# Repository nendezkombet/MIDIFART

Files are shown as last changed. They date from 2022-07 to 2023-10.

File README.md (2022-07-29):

# MIDIFART
Pocket midi controller

MIDIFART is a pocket midi controller designed for Arduino Promini that supports five analog potentiometer, 10 buttons, 1 bank button, some modules and midi output capability via 3.5mm TRS cable for sending data out to hardware synthesizer or midi device, and some modules supported. For programing code can be done with arduinoIDE. The PCB board also support Arduino Promicro as midi device for software controller but sadly you don't have full features like some optional module but it is more than enough for backing up your task. 

Designer and maintainer: [sandipratama/nendezkombet](https://github.com/nendezkombet) 

## Table of contents

- [Features](#features)
- [Midifart](#midifart)
- [PCB](#pcb)
- [BOM](#bom)
- [Case](#case)
- [Assembly Guide](#assembly-guide)

## Features

- Low cost build.
- Multi layout support.
- Easy to source components.
- Easy to build.
- Arduino Promini and Promicro compatible.
- 10 buttons with RGB support.
- 6 analog potentiometer support.
- Midi out support.
- Oled lcd support.
- Battery powered support ( as portable controller ).
- And more.

## Midifart

IMG_E0225



## PCB

Top view

IMG_E0231

Bottom view

IMG_E0233

## BOM

|Parts|Footprint|Quantity|
|:---|:---|:---|
|WS2812B RGB LED |5050|10|
|100nF capacitor|0805|10|
|12mm tactile switch |4 pin|10|
|12mm tactile switch caps ||10|
|6x10mm tactile switch|4 pin|1|
|Arduino Promini or Promicro |3.3v or 5v|1|
|10K pullup resistor (optional)|axial or 0805|11| 
|220ohm resistor (depend on mcu voltage)|axial or 0805|4| 
|10ohm resistor (depend on mcu voltage)|axial or 0805|1| 
|22ohm resistor (depend on mcu voltage)|axial or 0805|1| 
|B10K Analog potentiometer | RV09 or RK09|5|
|3.5mm TRS female socket |PJ313|1|
|Micro slide switch (optional)|MSS22D18 |1|
|3.7v-9V battery pack (depend on mcu voltage)||1|
|8mm M3 "MALE TO FEMALE" brass standoff||4|
|12mm M3 "FEMALE TO FEMALE" brass standoff||4|
|6mm M3 screw|-|8|
|SSD1306 oled lcd (optional)|0.96 inch|1| 
|HC-SR04 (optional)|distance module |1| 
|3mm led (optional)|mono color|2| 
|2pin molex socket|2.54 pitch|1|
|3.5mm TRS jack to 5-pin midi din male socket|see detail below|1|

51kXivjBTuL _AC_SX425_

you can build by your self, wiring instruction can by found out there.

Male TRS jack to female TRS jack socket wiring  :

|Male|Female|
|:---|:---|
|Tip | VCC |
|Ring | TX |
|Sleeve  | GROUND |

Because there are a few Promini variant, so for this project i recomended using compatible Promini variant and pinout configuration like in the picture below :

ha-7006-027-2

If you decide use Arduino Promini 3.3v or 5v you will need USB to TTL converter like in picture below :

"DO NOT FORGET CHECKING THE VOLTAGE SWITCH MUST BE MATCHING WITH YOUR MCU OPERATING VOLTAGE !!!"

ft232rl-ftdi-usb-zu-ttl-serial-adapter-modul-33v-5v

## Case

Use 3mm acrylic plate like pictures above.

## Assembly Guide

See inside "case" folder !!!

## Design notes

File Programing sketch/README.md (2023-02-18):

Before you upload the code into controller you need install some arduinoIDE library.
library requirements :

- Control Surface library https://github.com/tttapa/Control-Surface
- USB MIDI library https://github.com/arduino-libraries/MIDIUSB
- Fastled libray
- NewPing library if use ultrasonic sensor

Note :
in this project i'm not expert programer, i spent abouth sixth months just for learning programing language, electrical wiring and PCB design because my curiosity.
But at least i has so much fun and learn something new.
So if anyone expert with programing code maybe can help developeing this project at least tidy up my code are very wellcomed.
And will keep this project update.
for further updated i planed adding midi input and some features.

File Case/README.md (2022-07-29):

MIDIFART Assembly guide.

1. Prepare all the components and see PCB legend below for components pacement
2. solder pin header first ( just pin header without MCU )
3. Solder 100nf capacitors ( this is optional component )
4. Solder RGB leds if use ( this is optional component )
5. Solder all components that placed in the top of MCU ( make sure no component leave behind )
6. Than go on with other parts
7. If all done double check everything especialy for solder joint
8. Solder your MCU, because this part permanently attached in the PCB just make sure no mistake in every step you did before.
9. Upload program code to MCU and test the device





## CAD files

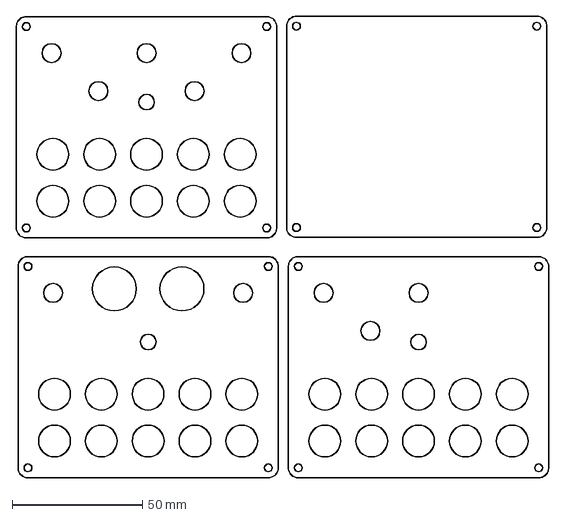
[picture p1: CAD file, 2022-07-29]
Case/midifart plate dxf.dxf
204.5 x 177.3 mm

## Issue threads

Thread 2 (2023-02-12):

Consultation on related issues

bobvc133, 2023-02-12:
1. Can you explain item 4 in detail? The resistors and soldering positions used by 5V MCU, and the resistors and soldering positions used by 3.3V MCU, I am a bit confused.
2. How to charge the battery?
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

nendezkombet, 2023-02-13:
hi, if you used 3.3v MCU you need 10ohm resistor and 22ohm resistor and look at the bottom legend  like in the picture above there are two resistor for TRS jack midi connection **"the left side for 10ohm resistor and 22ohm resistor for the right side"** resistor do not have polarity so just solder them, If you used 5v MCU just replace them with 2x 220ohm resistor.

For battery you need detach the battery from controller and charge with charging module like TP4056 or other variant. if i have a time i will upgrade this project including onboard charging module and midi input features.

bobvc133, 2023-02-13:
I use a 5V MCU to upload the program at the same time, but there is no response to the BUTTON1 operation, there is no problem with the line, I don’t know why

nendezkombet, 2023-02-13:
did you mean you use other arduino like nano or uno to upload the sketch to 3.3v promini ? make sure you connect VCC pin on promini to 3.3v on the uno/nano. Than in the IDE select promini with 8Mhz 3.3v varian and upload the sketch.

It's weird if the first button doesn't work, if you have multimeter you can check the switch connection maybe defected switch and try desolder and replace with spare switch you own.

bobvc133, 2023-02-13:
I'm using a 5V promini, and there is no problem with the multimeter test switch and wiring, which is very strange.

bobvc133, 2023-02-14:
Well, I thought of this reason too, but I haven't had time to test it because I don't have a proper power supply, thanks again!

nendezkombet, 2023-02-16:
it's weird, mine working well. Maybe the connection between switch to MCU or MCU breakout to the chip controller.

bobvc133, 2023-02-17:
The promini onboard LED responds when button 1 is operated

nendezkombet, 2023-02-18:
when button1 pressed do actualy sending data? and check the sketch one more time if you miss something!

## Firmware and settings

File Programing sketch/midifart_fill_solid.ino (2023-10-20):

#include <FastLED.h>
#include <Control_Surface.h>


USBMIDI_Interface midi;                                 // uncomment jika menggunakan promicro sebagai USB HID MIDI sebagai software controller
                                                        // uncomment line dibawah ini jika controller di fungsikan sebagai hardware controller                                            
//HardwareSerialMIDI_Interface midi {Serial};           // setting awal serial midi untuk promini yang digunakan dengan 5pin midi din sebagai hardware controller
                                                        // ubah "Serial" ke "Serial1" jika menggunakan promicro dengan 5pin midi din sebagai hardware controller

#define NUM_LEDS 10
#define DATA_PIN 9 
#define FRAMES_PER_SECOND  120
CRGB leds[NUM_LEDS];

CCPotentiometer potentiometers[]= {
  {A3, 75},             // parameter pin potentiometer arduino dan midi CC yang digunakan
  {A2, 74},             // midi CC bisa di ubah sesuai yang di inginkan
  {A1, 73},
  {A0, 72}, 
  {A6, 71}              // A7 pin untuk promini potentiometer ke-5 dan A6 pin untuk promicro potentiometer ke-5  
};

Button buttons[] {
  //13, 10, 3, 8, 5, 12, 11, 2, 7, 6            // array pin dari promini buttons
  15, 10, 3, 8, 5, 14, 16, 2, 7, 6              // array pin dari promicro buttons
};

Button selector = 0;              // Bank selector button
int buttonPushCounter = 0;        // Selector button counter
int buttonState = 0;              // posisi button
int lastButtonState = 0;          // posisi button sebelumnya

template <class T, size_t N> constexpr size_t len(const T (&)[N]) { return N; }

static_assert(len(buttons) == (len(leds)),"midifart");

void setup() {
  
  FastLED.addLeds<WS2812B, DATA_PIN, GRB>(leds, NUM_LEDS); 
  FastLED.setBrightness (40); 
  FastLED.clear();  
  delay(50);
  fill_solid(leds, NUM_LEDS, CRGB::Aqua);
  FastLED.show();
 
  
  Control_Surface.begin();
  //midi.begin();
  for (auto &button : buttons)
  button.begin();
  Keyboard.begin();
}

void loop() {

  Control_Surface.loop();
  
  buttonState = selector.update() == Button::Falling;           // Update pushbutton selector:

  if (buttonState != lastButtonState) {                         // Pembanding status button dengan status sebelumnya
    if (buttonState == selector.update() == Button::Rising) {
      buttonPushCounter++;
    }
  }

  lastButtonState = buttonState;                                
  if (buttonPushCounter % 4 == 0) {                             
    buttonPushCounter = 0;
    }

  switch (buttonPushCounter) {

    case 0 : 
    tonemode1();
    FastLED.setBrightness (20); 
    fill_solid(leds, NUM_LEDS, CRGB::Aqua);
    FastLED.show();    
    

    break;
    
    case 1 : 
    tonemode2();
    FastLED.setBrightness (40); 
    fill_solid(leds, NUM_LEDS, CRGB::Olive);
    FastLED.show();    

    break;
    
    case 2 : 
    tonemode3();
    FastLED.setBrightness (30); 
    fill_solid(leds, NUM_LEDS, CRGB::Crimson);
    FastLED.show();    
 
    break;

    case 3 : 
    tonemode4();
    FastLED.setBrightness (30); 
    fill_solid(leds, NUM_LEDS, CRGB::Red);
    FastLED.show();    
 
    break;
      }
}


void ccmode() {
  // ketiga constant parameter dibawah sangat berguna jika digunakan untuk mengirim beberapa command secara bersamaan contohnya MSB dan LSB
  // just change the array value as you need
  
  const uint8_t cc[]    { 12, 13, 14, 15, 16, 17, 18, 19, 28, 29 };
  const uint8_t val[]   { 127, 127, 127, 127, 127, 127, 127, 127, 127, 127 };    
  //const uint8_t pc[]    { 0, 1, 2, 3, 4, 5, 6, 7, 8, 9 };
  
  for (uint8_t i = 0; i < len(buttons); ++i) {
    auto state = buttons[i].update();
    if (state == Button::Falling) {
      
      Control_Surface.sendControlChange(cc[i],val[i]);            // Command untuk mengirim midi CC dengan nilai spesifik
      //Control_Surface.sendProgramChange(pc[i]);                 // Kunjungi dokumentasi Control Surface library untuk informasi lebih lanjut
    }
  }
}

void tonemode1() {
  //const uint8_t cc[]  { 32, 32, 32, 32, 32, 32, 32, 32, 32, 32 };
  //const uint8_t val[] { 1, 2, 3, 4, 5, 1, 2, 3, 4, 5 }; 
  //const uint8_t pc[]  { 10, 11, 12, 13, 14, 15, 16, 17, 18, 19 };
  const MIDIAddress noteAddress[]  {{MIDI_Notes::C(3), CHANNEL_1},
                                  {MIDI_Notes::Db(3), CHANNEL_1},
                                  {MIDI_Notes::D(3), CHANNEL_1},
                                  {MIDI_Notes::Eb(3), CHANNEL_1},
                                  {MIDI_Notes::E(3), CHANNEL_1},
                                  {MIDI_Notes::F_(3), CHANNEL_1},
                                  {MIDI_Notes::Gb(3), CHANNEL_1},
                                  {MIDI_Notes::G(3), CHANNEL_1},
                                  {MIDI_Notes::Ab(3), CHANNEL_1},
                                  {MIDI_Notes::A(3), CHANNEL_1}};
  const uint8_t onvelocity[]  { 127, 127, 127, 127, 127, 127, 127, 127, 127, 127 };
  //const uint8_t offvelocity[]  { 0, 0, 0, 0, 0, 0, 0, 0, 0, 0 };
  
  for (uint8_t i = 0; i < len(buttons); ++i) {
    auto state = buttons[i].update();
    if (state == Button::Falling) {
      //Control_Surface.sendControlChange(cc[i],val[i]);
      //Control_Surface.sendProgramChange(pc[i]);
      Control_Surface.sendNoteOn(noteAddress[i], onvelocity[i]);         // send a note dengan spesifik value
    } else if (state == Button::Rising) {
      Control_Surface.sendNoteOff(noteAddress[i], onvelocity[i]); 
      }
  }
}

void tonemode2() {
  //const uint8_t cc[]  { 32, 32, 32, 32, 32, 32, 32, 32, 32, 32 };
  //const uint8_t val[] { 1, 2, 3, 4, 5, 1, 2, 3, 4, 5 }; 
  //const uint8_t pc[]  { 10, 11, 12, 13, 14, 15, 16, 17, 18, 19 };
  const MIDIAddress noteAddress[] {{MIDI_Notes::Bb(3), CHANNEL_1},
                                  {MIDI_Notes::B(3), CHANNEL_1},
                                  {MIDI_Notes::C(4), CHANNEL_1},
                                  {MIDI_Notes::Db(4), CHANNEL_1},
                                  {MIDI_Notes::D(4), CHANNEL_1},
                                  {MIDI_Notes::Eb(4), CHANNEL_1},
                                  {MIDI_Notes::E(4), CHANNEL_1},
                                  {MIDI_Notes::F_(4), CHANNEL_1},
                                  {MIDI_Notes::Gb(4), CHANNEL_1},
                                  {MIDI_Notes::G(4), CHANNEL_1}};
  const uint8_t onvelocity[]  { 127, 127, 127, 127, 127, 127, 127, 127, 127, 127 };
  //const uint8_t offvelocity[]  { 0, 0, 0, 0, 0, 0, 0, 0, 0, 0 };
  
  for (uint8_t i = 0; i < len(buttons); ++i) {
    auto state = buttons[i].update();
    if (state == Button::Falling) {
      //Control_Surface.sendControlChange(cc[i],val[i]);
      //Control_Surface.sendProgramChange(pc[i]);
      Control_Surface.sendNoteOn(noteAddress[i], onvelocity[i]);         // send a note dengan spesifik value
    } else if (state == Button::Rising) {
      Control_Surface.sendNoteOff(noteAddress[i], onvelocity[i]); 
      }
  }
}

void tonemode3() {
  //const uint8_t cc[]  { 32, 32, 32, 32, 32, 32, 32, 32, 32, 32 };
  //const uint8_t val[] { 1, 2, 3, 4, 5, 1, 2, 3, 4, 5 }; 
  //const uint8_t pc[]  { 10, 11, 12, 13, 14, 15, 16, 17, 18, 19 };
  const MIDIAddress noteAddress[]  {{MIDI_Notes::Ab(4), CHANNEL_1},
                                  {MIDI_Notes::A(4), CHANNEL_1},
                                  {MIDI_Notes::Bb(4), CHANNEL_1},
                                  {MIDI_Notes::B(4), CHANNEL_1},
                                  {MIDI_Notes::C(5), CHANNEL_1},
                                  {MIDI_Notes::Db(5), CHANNEL_1},
                                  {MIDI_Notes::D(5), CHANNEL_1},
                                  {MIDI_Notes::Eb(5), CHANNEL_1},
                                  {MIDI_Notes::E(5), CHANNEL_1},
                                  {MIDI_Notes::F_(5), CHANNEL_1}};
  const uint8_t onvelocity[]  { 127, 127, 127, 127, 127, 127, 127, 127, 127, 127 };
  //const uint8_t offvelocity[]  { 0, 0, 0, 0, 0, 0, 0, 0, 0, 0 };
  
  for (uint8_t i = 0; i < len(buttons); ++i) {
    auto state = buttons[i].update();
    if (state == Button::Falling) {
      //Control_Surface.sendControlChange(cc[i],val[i]);
      //Control_Surface.sendProgramChange(pc[i]);
      Control_Surface.sendNoteOn(noteAddress[i], onvelocity[i]);         // send a note dengan spesifik value 
    } else if (state == Button::Rising) {
      Control_Surface.sendNoteOff(noteAddress[i], onvelocity[i]); 
      }
  }
}

void tonemode4() {
  //const uint8_t cc[]  { 32, 32, 32, 32, 32, 32, 32, 32, 32, 32 };
  //const uint8_t val[] { 1, 2, 3, 4, 5, 1, 2, 3, 4, 5 }; 
  //const uint8_t pc[]  { 10, 11, 12, 13, 14, 15, 16, 17, 18, 19 };
  const MIDIAddress noteAddress[]  {{MIDI_Notes::Gb(5), CHANNEL_1},
                                  {MIDI_Notes::G(5), CHANNEL_1},
                                  {MIDI_Notes::Ab(5), CHANNEL_1},
                                  {MIDI_Notes::A(5), CHANNEL_1},
                                  {MIDI_Notes::Bb(5), CHANNEL_1},
                                  {MIDI_Notes::B(5), CHANNEL_1},
                                  {MIDI_Notes::C(6), CHANNEL_1},
                                  {MIDI_Notes::Db(6), CHANNEL_1},
                                  {MIDI_Notes::D(6), CHANNEL_1},
                                  {MIDI_Notes::Eb(6), CHANNEL_1}};
  const uint8_t onvelocity[]  { 127, 127, 127, 127, 127, 127, 127, 127, 127, 127 };
  //const uint8_t offvelocity[]  { 0, 0, 0, 0, 0, 0, 0, 0, 0, 0 };
  
  for (uint8_t i = 0; i < len(buttons); ++i) {
    auto state = buttons[i].update();
    if (state == Button::Falling) {
      //Control_Surface.sendControlChange(cc[i],val[i]);
      //Control_Surface.sendProgramChange(pc[i]);
      Control_Surface.sendNoteOn(noteAddress[i], onvelocity[i]);         // send a note dengan spesifik value 
    } else if (state == Button::Rising) {
      Control_Surface.sendNoteOff(noteAddress[i], onvelocity[i]); 
      }
  }
}

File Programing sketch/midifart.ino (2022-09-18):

#include <FastLED.h>
//#include <NewPing.h>              //uncomment this line if use ultrasonic sensor
#include <Control_Surface.h>


//USBMIDI_Interface midi;                               // uncomment this line if use promicro as USB HID MIDI device as software controller
                                                        // and comment the line below                                                       
HardwareSerialMIDI_Interface midi {Serial};             // default serial midi for promini with 5pin midi din as hardware controller
                                                        // change "Serial" to "Serial1" if you using promicro with 5pin midi din as hardware controller
                                                      
//uncomment all of six line below if you using ultrasonic sensor (only works with promini)                                                     
//#define TRIGGER_PIN  18           // Arduino pin tied to trigger pin on the ultrasonic sensor.
//#define ECHO_PIN     19           // Arduino pin tied to echo pin on the ultrasonic sensor.
//#define MAX_DISTANCE 30           // Maximum distance we want to ping, change this value if necessary (in centimeters)
//int midiMapped = 0;          
//int lastmidiMapped = 0;
//NewPing sonar(TRIGGER_PIN, ECHO_PIN, MAX_DISTANCE);           // NewPing setup of pins and maximum distance.

#define NUM_LEDS 10
#define DATA_PIN 9 
#define FRAMES_PER_SECOND  120
CRGB leds[NUM_LEDS];

int ledState = LOW;
unsigned long previousMillis = 0;
const long interval = 1000; 

CCPotentiometer potentiometers[]= {
  {A3, 11},    // pin address and CC address parameter
  {A2, 74},    // CC address parameter can be edited if you need specific CC address
  {A1, 73},
  {A0, 75}, 
  {A7, 5}      // A7 pin for promini fifth pot and A6 pin for promicro fifth pot
};

Button buttons[] {
  13, 10, 3, 8, 5, 12, 11, 2, 7, 6          // array of promini buttons
  //15, 10, 3, 8, 5, 14, 16, 2, 7, 6        // array of promicro buttons
};

Button selector = 0;         // Bank selector button
int buttonPushCounter = 0;   // counter for the number of button presses
int buttonState = 0;         // current state of the button
int lastButtonState = 0;     // previous state of the button

template <class T, size_t N> constexpr size_t len(const T (&)[N]) { return N; }

static_assert(len(buttons) == (len(leds)),"midifart");

void setup() {
  
  FastLED.addLeds<WS2812B, DATA_PIN, GRB>(leds, NUM_LEDS); 
  FastLED.setBrightness (100);  

  pinMode(18, OUTPUT);      // bank led indicator (promini only)
  pinMode(19, OUTPUT);
  
  Control_Surface.begin();
  midi.begin();
  for (auto &button : buttons)
  button.begin();
}

void loop() {

  Control_Surface.loop();
  
  unsigned long currentMillis = millis(); 
  buttonState = selector.update() == Button::Falling;        // read the pushbutton selector:

  if (buttonState != lastButtonState) {                      //compare the buttonState to its previous state
    if (buttonState == selector.update() == Button::Rising) {
      buttonPushCounter++;
    }
  }

  lastButtonState = buttonState;                             // save the current state as the last state

  if (buttonPushCounter % 3 == 0) {                          // change value "3" to "2" if you just need two bank without sysex mode
    buttonPushCounter = 0;
    }

  switch (buttonPushCounter) {

    case 0 : 
    bank1();
    
  if (currentMillis - previousMillis >= interval) {
    // save the last time you blinked the LED
    previousMillis = currentMillis;

    // if the LED is off turn it on and vice-versa:
    if (ledState == LOW) {
      ledState = HIGH;
    } else {
      ledState = LOW;
    }

    // set the LED with the ledState of the variable:
    digitalWrite(18, ledState);
    digitalWrite(19, LOW);
  } 
    break;
    
    case 1 : 
    bank2();
    
  if (currentMillis - previousMillis >= interval) {
    // save the last time you blinked the LED
    previousMillis = currentMillis;

    // if the LED is off turn it on and vice-versa:
    if (ledState == LOW) {
      ledState = HIGH;
    } else {
      ledState = LOW;
    }

    // set the LED with the ledState of the variable:
    digitalWrite(19, ledState);
    digitalWrite(18, LOW);
  }
    break;
    
    case 2 : 
    sysExmode();
    
  if (currentMillis - previousMillis >= interval) {
    // save the last time you blinked the LED
    previousMillis = currentMillis;

    // if the LED is off turn it on and vice-versa:
    if (ledState == LOW) {
      ledState = HIGH;
    } else {
      ledState = LOW;
    }

    // set the LED with the ledState of the variable:
    digitalWrite(18, ledState);
    digitalWrite(19, ledState);
  }   
    break;
  }
}
    
  //uncomment all of seven line below if you using ultrasonic sensor (only works with promini)
  //float x  = sonar.ping_cm();                          //sensor read
  //midiMapped = map(x, 5, 28, 127, 0);                  //sensor map 5-28 cm converted to cc value 0-127 or 127-0
  //if (lastmidiMapped != midiMapped) {
  //       if (midiMapped >= 0 && midiMapped <= 127) 
  //       midi.sendControlChange(42, midiMapped);        
  //       lastmidiMapped = midiMapped;                  //save last cc value
  //}


void bank1() {
  // three constant parameter below very convenient if you need specific sound between bank to bank or working with MSB and LSB
  // just change the array value as you need
  
  const uint8_t cc[]    { 32, 32, 32, 32, 32, 32, 32, 32, 32, 32 };
  const uint8_t val[]   { 1, 2, 3, 4, 5, 1, 2, 3, 4, 5 };    
  const uint8_t pc[]    { 0, 1, 2, 3, 4, 5, 6, 7, 8, 9 };
  
  for (uint8_t i = 0; i < len(buttons); ++i) {
    auto state = buttons[i].update();
    if (state == Button::Falling) {
      midi.sendControlChange(cc[i],val[i]);       // this command for sending CC folowed by Program Change
      midi.sendProgramChange(pc[i]);              // there are lot midi command like sending Pitcbend value and other 
      FastLED.clear();                            // just see Control Surface library documentation
      leds[i] = CRGB::Red;
      FastLED.show();
      //Serial.println(i); 
    }
  }
}

void bank2() {
  const uint8_t cc[]  { 32, 32, 32, 32, 32, 32, 32, 32, 32, 32 };
  const uint8_t val[] { 1, 2, 3, 4, 5, 1, 2, 3, 4, 5 }; 
  const uint8_t pc[]  { 10, 11, 12, 13, 14, 15, 16, 17, 18, 19 };
  
  for (uint8_t i = 0; i < len(buttons); ++i) {
    auto state = buttons[i].update();
    if (state == Button::Falling) {
      midi.sendControlChange(cc[i],val[i]);
      midi.sendProgramChange(pc[i]);
      FastLED.clear();
      leds[i] = CRGB::Blue;
      FastLED.show();
      //Serial.println(i); 
    }
  }
}
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

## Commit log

2022-06-26 gerber upload
2022-07-27 gerber added
